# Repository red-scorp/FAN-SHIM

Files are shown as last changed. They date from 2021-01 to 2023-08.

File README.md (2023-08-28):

# FAN-SHIM project

FAN-SHIM (mini-HAT), support board for axial fans to cool Raspberry Pi.

Some Pis not require cooling because their CPUs are running in low performance mode.
Some Pis are good with simple passive heat sinks alone.
It's generally recommended to use active coolers, specially if you run Pi's CPU over-clocked.

This boards are designed to be used with standard axial funs with Pi's "Dupont" and standard PC's "Molex" connectors.

## FAN-zero30-SHIM

Raspberry Pi zero 40-pin **FAN-zero30-SHIM** mini-HAT.

Preview:

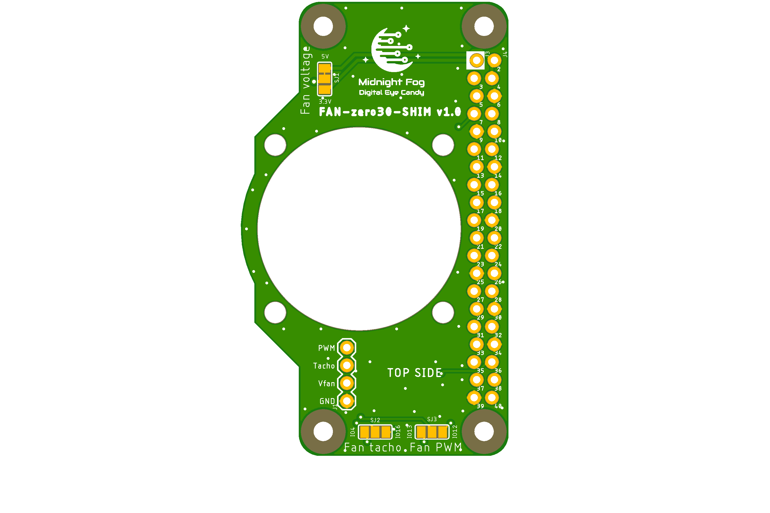
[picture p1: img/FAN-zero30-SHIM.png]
FAN-zero30-SHIM preview


[Schematics in PDF format](doc/FAN-zero30-SHIM.pdf)

Features:

- locked Pi headers
- 30mm axial fan
- 5V and 3.3V fan power selection
- fan tacho and PWM signal selection
- Pi zero board style
- can be used as SHIM (no headers) or HAT (with headers)

Pins Configuration:

|Fan Pin |Option 1 |Option 2 |
|---|---|---|
|Vfan |5V\* |3.3V |
|tacho |GPIO16 |GPIO4 |
|PWM |GPIO12 |GPIO13 |

\*) the pin is connected by default.

CAM files are available.

## FAN-zero25-SHIM

Raspberry Pi zero 40-pin **FAN-zero25-SHIM** mini-HAT.

Preview:

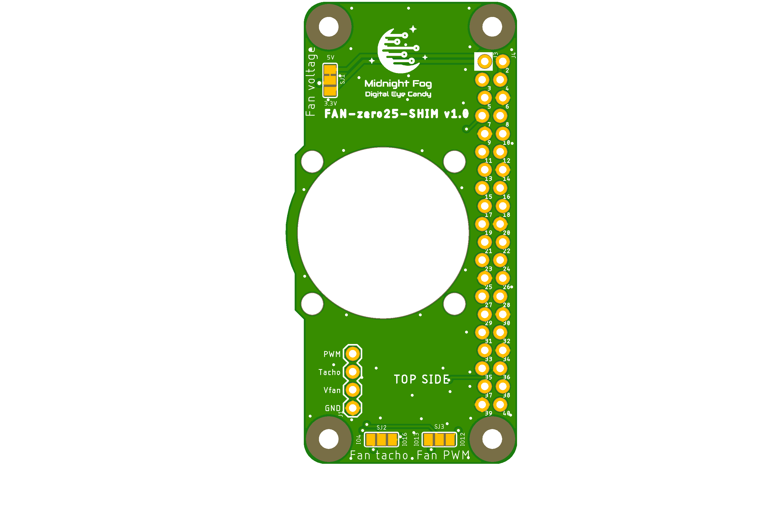
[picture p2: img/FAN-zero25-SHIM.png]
FAN-zero25-SHIM preview


[Schematics in PDF format](doc/FAN-zero25-SHIM.pdf)

Features:

- locked Pi headers
- 25mm axial fan
- 5V and 3.3V fan power selection
- fan tacho and PWM signal selection
- Pi zero board style
- can be used as SHIM (no headers) or HAT (with headers)

Pins Configuration:

|Fan Pin |Option 1 |Option 2 |
|---|---|---|
|Vfan |5V\* |3.3V |
|tacho |GPIO16 |GPIO4 |
|PWM |GPIO12 |GPIO13 |

\*) the pin is connected by default.

CAM files are available.

## FAN-zero20-SHIM

Raspberry Pi zero 40-pin **FAN-zero20-SHIM** mini-HAT.

Preview:

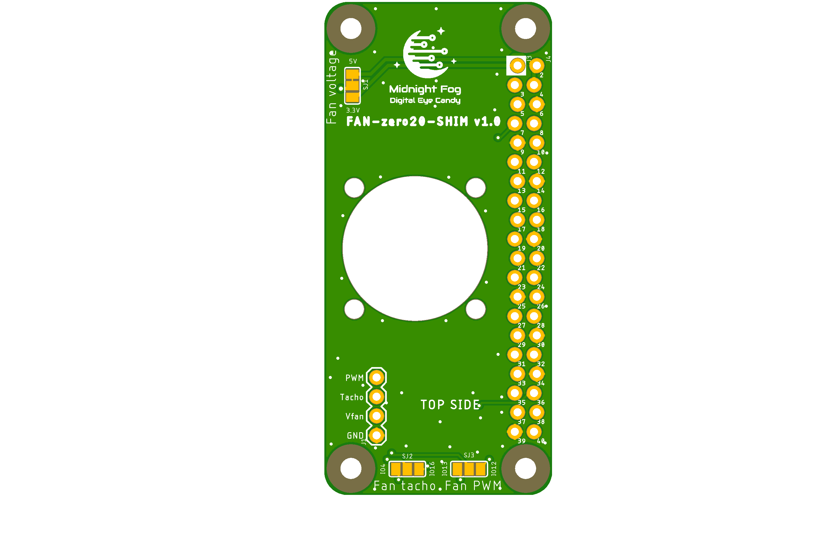
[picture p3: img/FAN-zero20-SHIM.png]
FAN-zero20-SHIM preview


[Schematics in PDF format](doc/FAN-zero20-SHIM.pdf)

Features:

- locked Pi headers
- 20mm axial fan
- 5V and 3.3V fan power selection
- fan tacho and PWM signal selection
- Pi zero board style
- can be used as SHIM (no headers) or HAT (with headers)

Pins Configuration:

|Fan Pin |Option 1 |Option 2 |
|---|---|---|
|Vfan |5V\* |3.3V |
|tacho |GPIO16 |GPIO4 |
|PWM |GPIO12 |GPIO13 |

\*) the pin is connected by default.

CAM files are available.

## FAN-plus40-SHIM

Raspberry Pi A+/B+ 40-pin **FAN-plus40-SHIM** mini-HAT.

Preview:

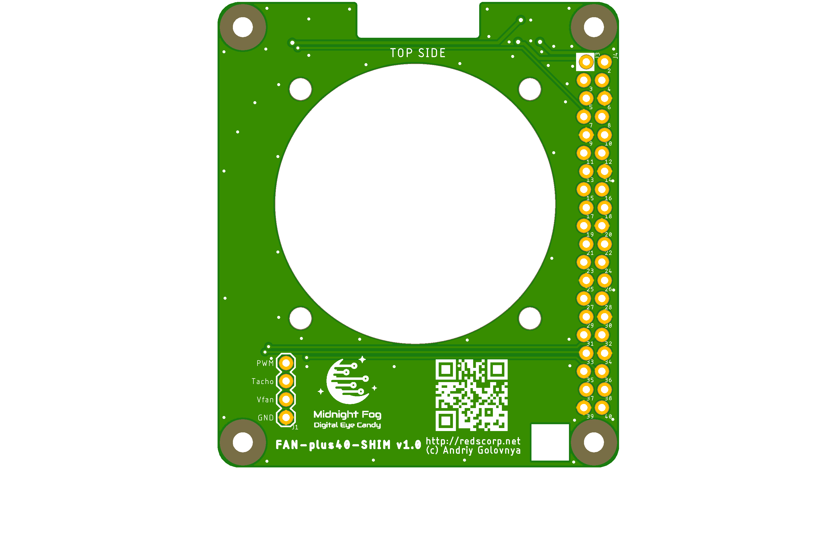
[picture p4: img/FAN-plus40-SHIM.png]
FAN-plus40-SHIM preview


[Schematics in PDF format](doc/FAN-plus40-SHIM.pdf)

Features:

- locked Pi headers
- 40mm axial fan
- 5V and 3.3V fan power selection
- fan tacho and PWM signal selection
- Pi A+/B+ board style
- can be used as SHIM (no headers) or HAT (with headers)

Pins Configuration:

|Fan Pin |Option 1 |Option 2 |
|---|---|---|
|Vfan |5V\* |3.3V |
|tacho |GPIO16 |GPIO4 |
|PWM |GPIO12 |GPIO13 |

\*) the pin is connected by default.

CAM files are available.

## FAN-plus30-SHIM

Raspberry Pi A+/B+ 40-pin **FAN-plus30-SHIM** mini-HAT.

Preview:

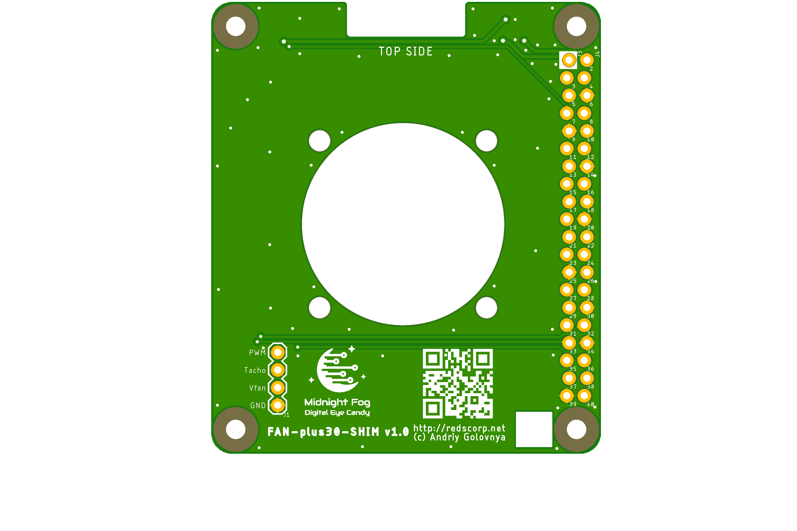
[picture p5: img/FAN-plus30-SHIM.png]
FAN-plus30-SHIM preview


[Schematics in PDF format](doc/FAN-plus30-SHIM.pdf)

Features:

- locked Pi headers
- 30mm axial fan
- 5V and 3.3V fan power selection
- fan tacho and PWM signal selection
- Pi A+/B+ board style
- can be used as SHIM (no headers) or HAT (with headers)

Pins Configuration:

|Fan Pin |Option 1 |Option 2 |
|---|---|---|
|Vfan |5V\* |3.3V |
|tacho |GPIO16 |GPIO4 |
|PWM |GPIO12 |GPIO13 |

\*) the pin is connected by default.

CAM files are available.

## Links

- [pinout.xyz](https://pinout.xyz/) - a brilliant resource on topic of Pi's pinout and HATs.
- [raspberrypi/hats](https://github.com/raspberrypi/hats) - Pi's HAT specification.

## How to help

Your contributions as code, resources, or finances are welcome! Please contact me directly via email at andriy.golovnya@gmail.com or through my [GitHub profile](https://github.com/red-scorp).

If you'd like to make a financial contribution, you can donate via [PayPal](http://paypal.me/redscorp) or [Ko-Fi](http://ko-fi.com/redscorp). Your support is greatly appreciated.

Thanks in advance!

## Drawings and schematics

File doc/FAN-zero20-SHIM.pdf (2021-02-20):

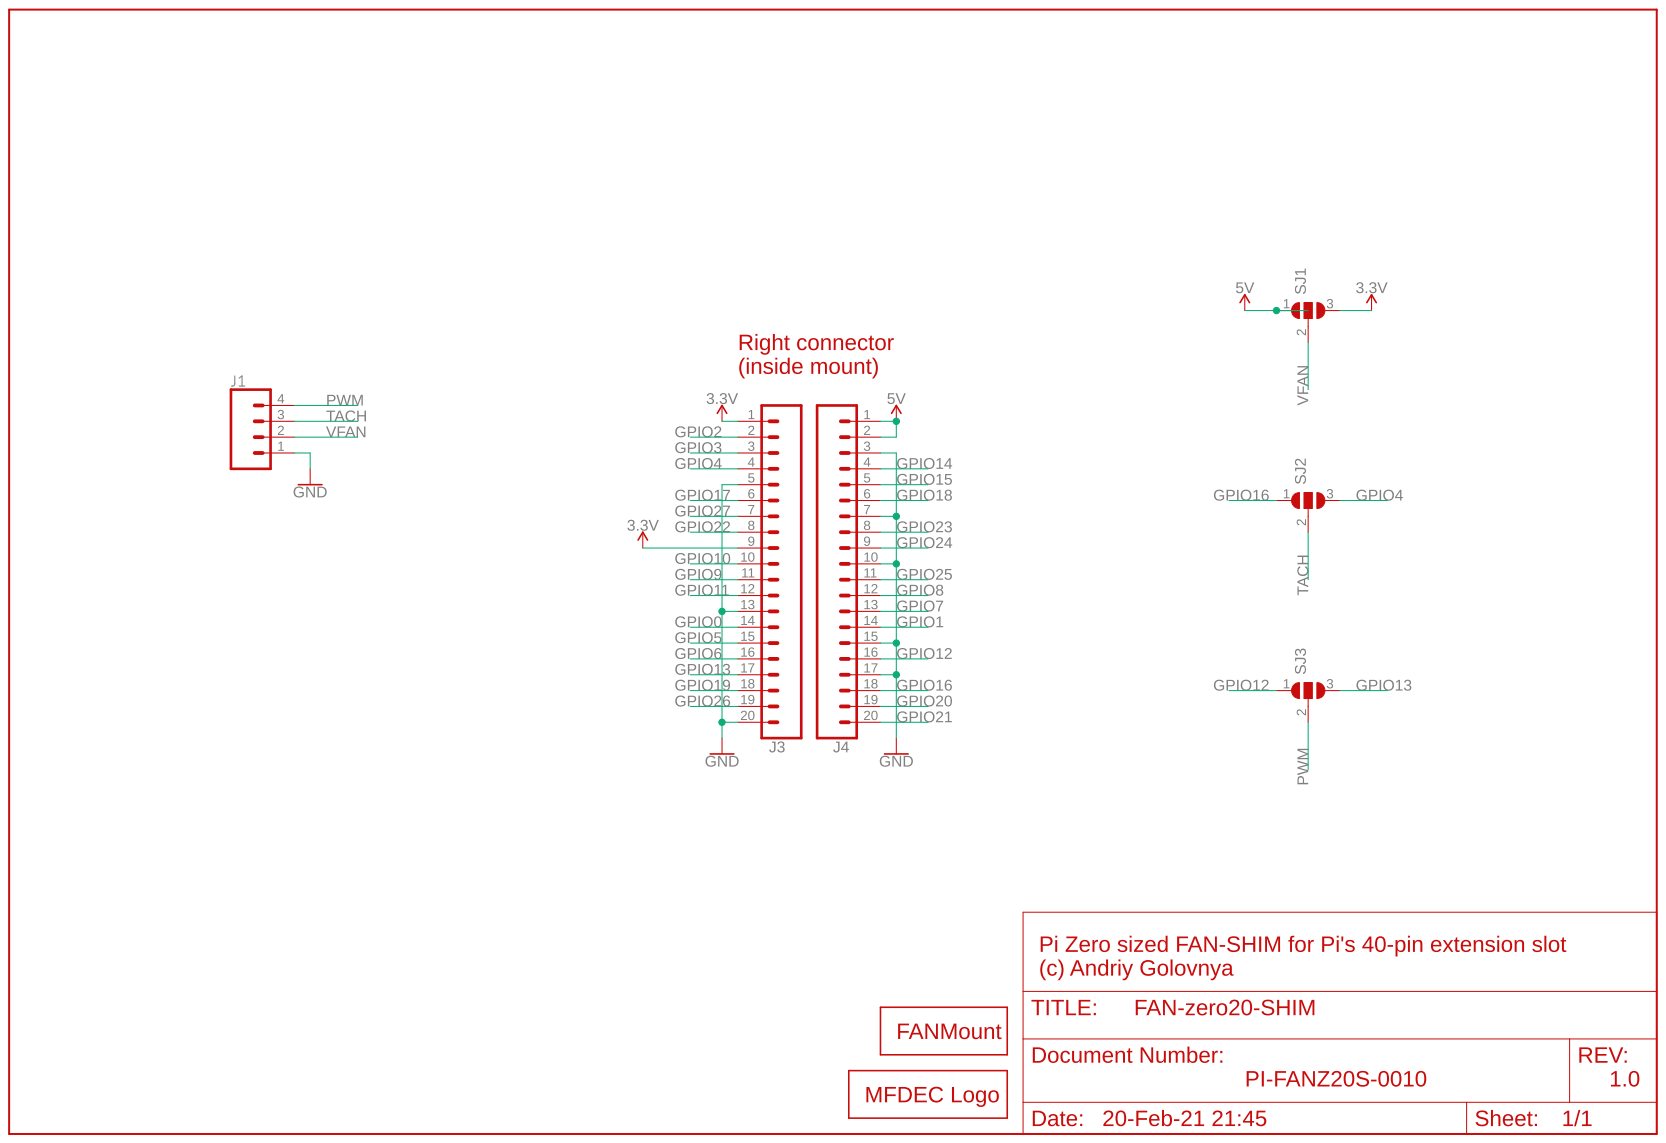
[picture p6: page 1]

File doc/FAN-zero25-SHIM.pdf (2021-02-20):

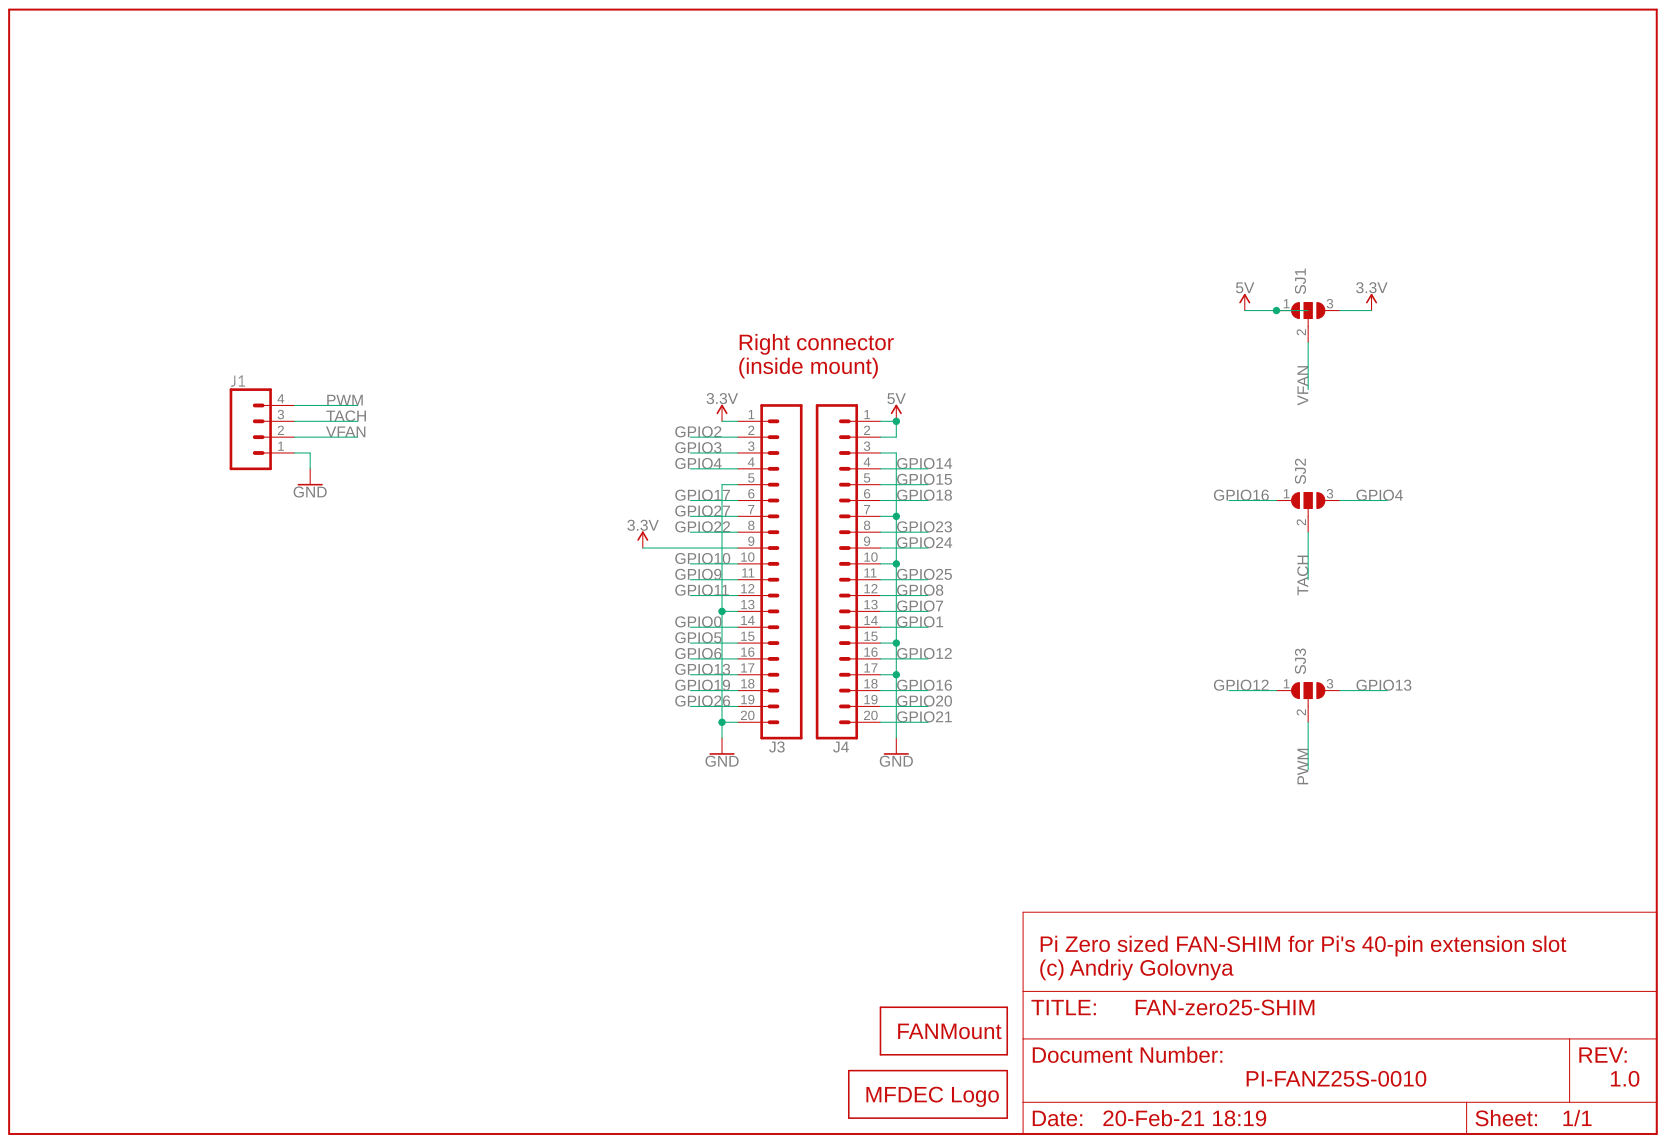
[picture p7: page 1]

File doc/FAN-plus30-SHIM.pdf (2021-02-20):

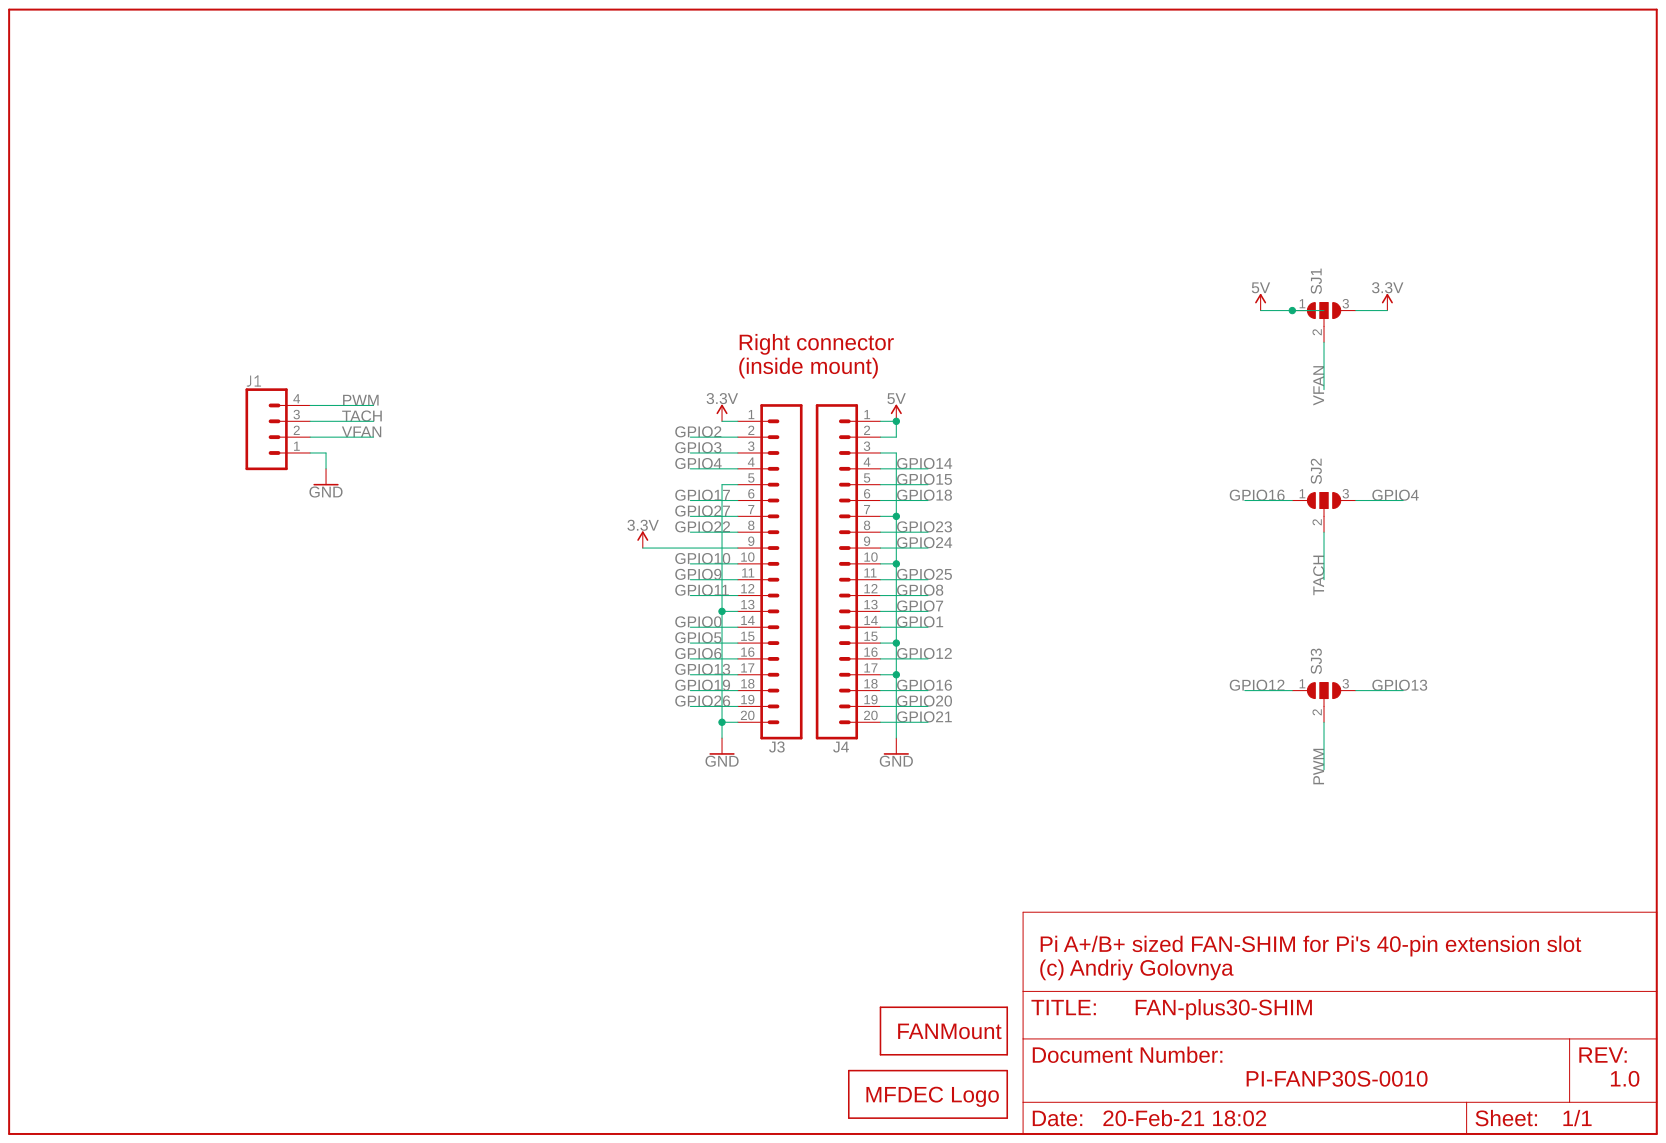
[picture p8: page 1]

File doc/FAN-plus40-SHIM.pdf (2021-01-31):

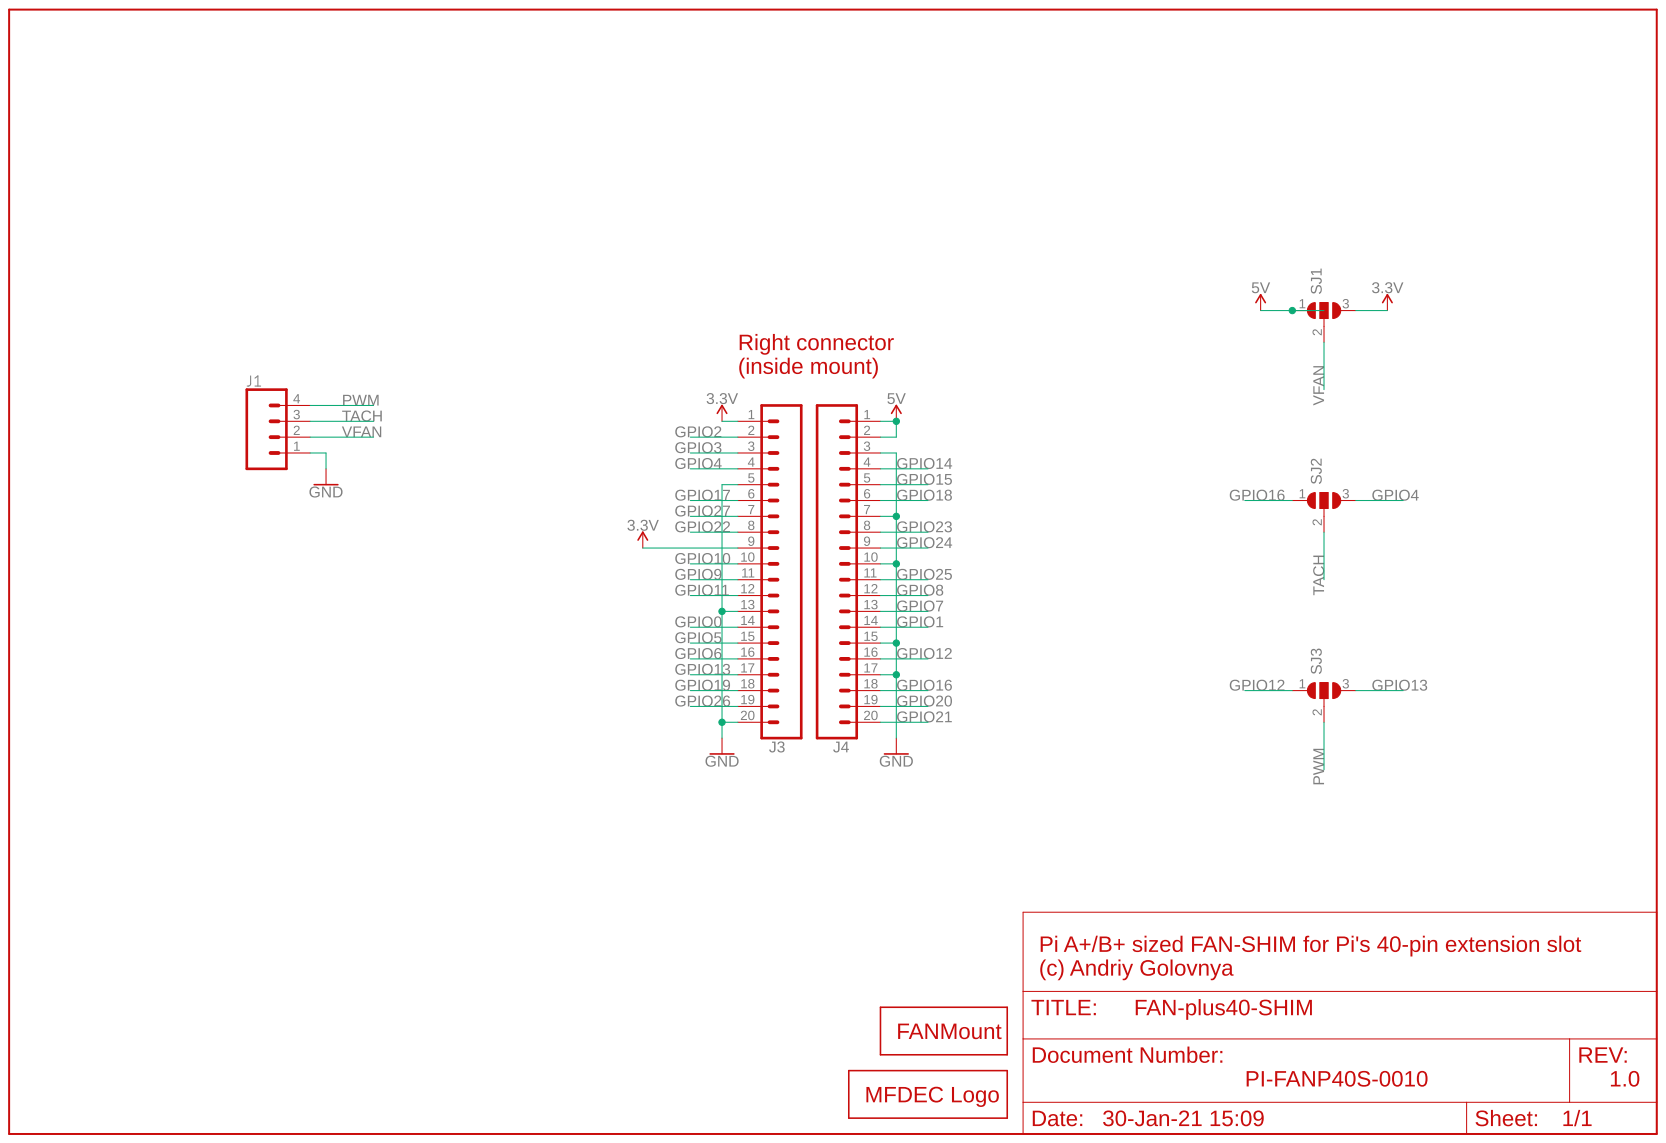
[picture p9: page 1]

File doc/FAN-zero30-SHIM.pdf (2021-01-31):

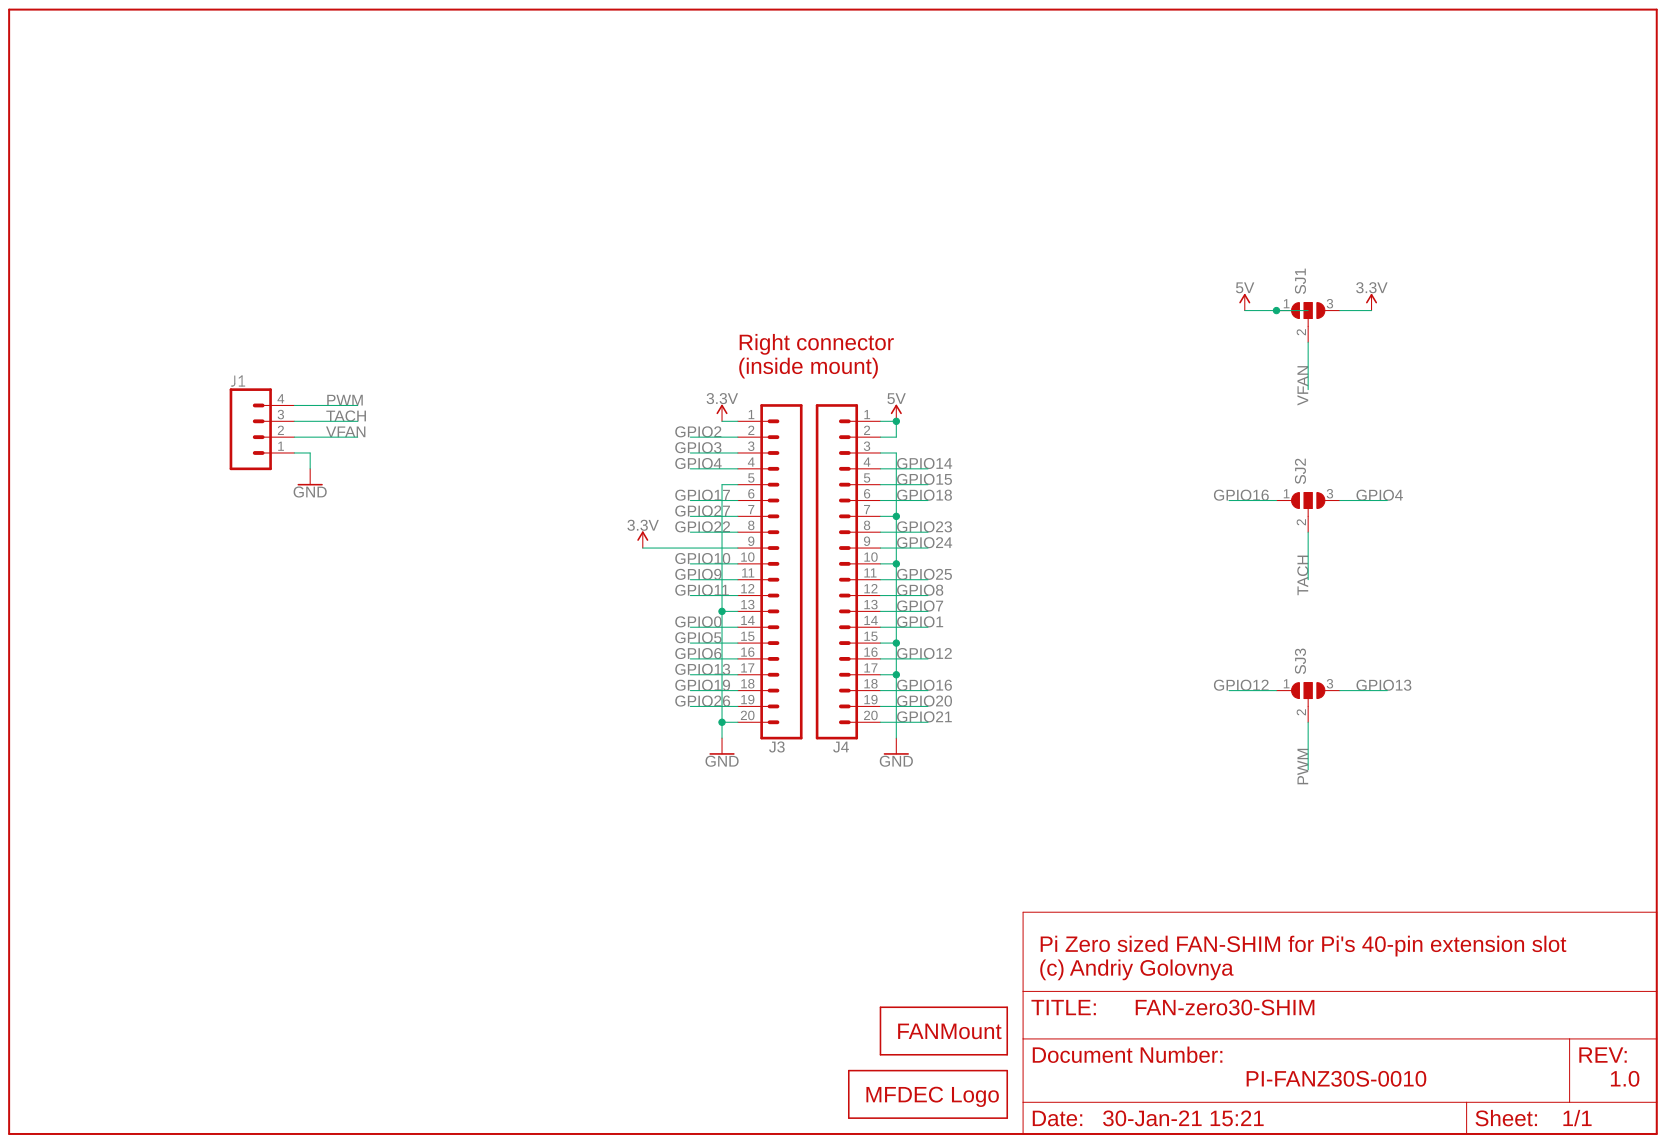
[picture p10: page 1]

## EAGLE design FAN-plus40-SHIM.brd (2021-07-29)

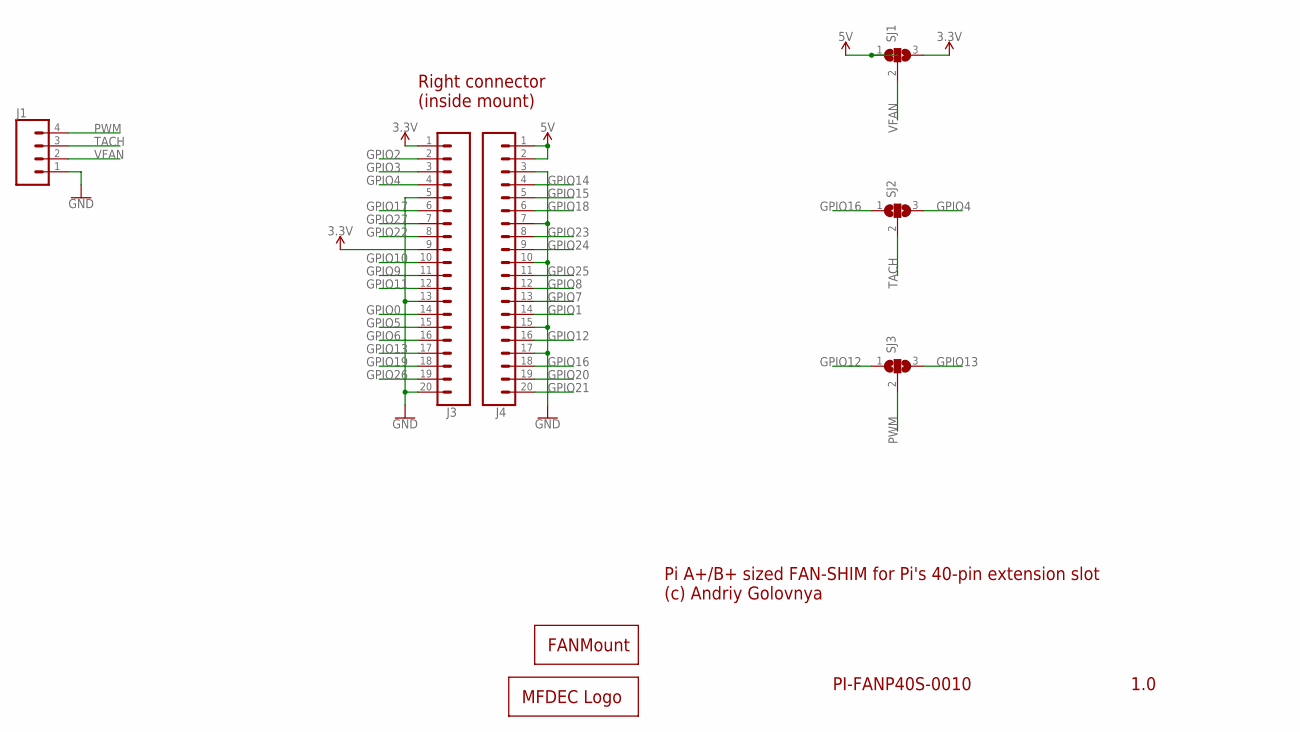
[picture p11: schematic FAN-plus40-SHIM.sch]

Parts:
FAN1: FAN40HO
J1: CONN_04; 1X04
J3, J4: CONN_20LOCK; 1X20_LOCK
LOGO1: MFDECLOGO_L_40MM; MFDEC_L_40MM
SJ1, SJ2, SJ3: SJ2; SJ_2

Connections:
3.3V: J3.1, J3.9, SJ1.3
5V: J4.1, J4.2, SJ1.1
GND: J1.1, J3.5, J3.13, J3.20, J4.3, J4.7, J4.10, J4.15, J4.17
GPIO0: J3.14
GPIO1: J4.14
GPIO2: J3.2
GPIO3: J3.3
GPIO4: J3.4, SJ2.3
GPIO5: J3.15
GPIO6: J3.16
GPIO7: J4.13
GPIO8: J4.12
GPIO9: J3.11
GPIO10: J3.10
GPIO11: J3.12
GPIO12: J4.16, SJ3.1
GPIO13: J3.17, SJ3.3
GPIO14: J4.4
GPIO15: J4.5
GPIO16: J4.18, SJ2.1
GPIO17: J3.6
GPIO18: J4.6
GPIO19: J3.18
GPIO20: J4.19
GPIO21: J4.20
GPIO22: J3.8
GPIO23: J4.8
GPIO24: J4.9
GPIO25: J4.11
GPIO26: J3.19
GPIO27: J3.7
PWM: J1.4, SJ3.2
TACH: J1.3, SJ2.2
VFAN: J1.2, SJ1.2

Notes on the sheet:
1.0
PI-FANP40S-0010
Pi A+/B+ sized FAN-SHIM for Pi's 40-pin extension slot (c) Andriy Golovnya
Right connector (inside mount)

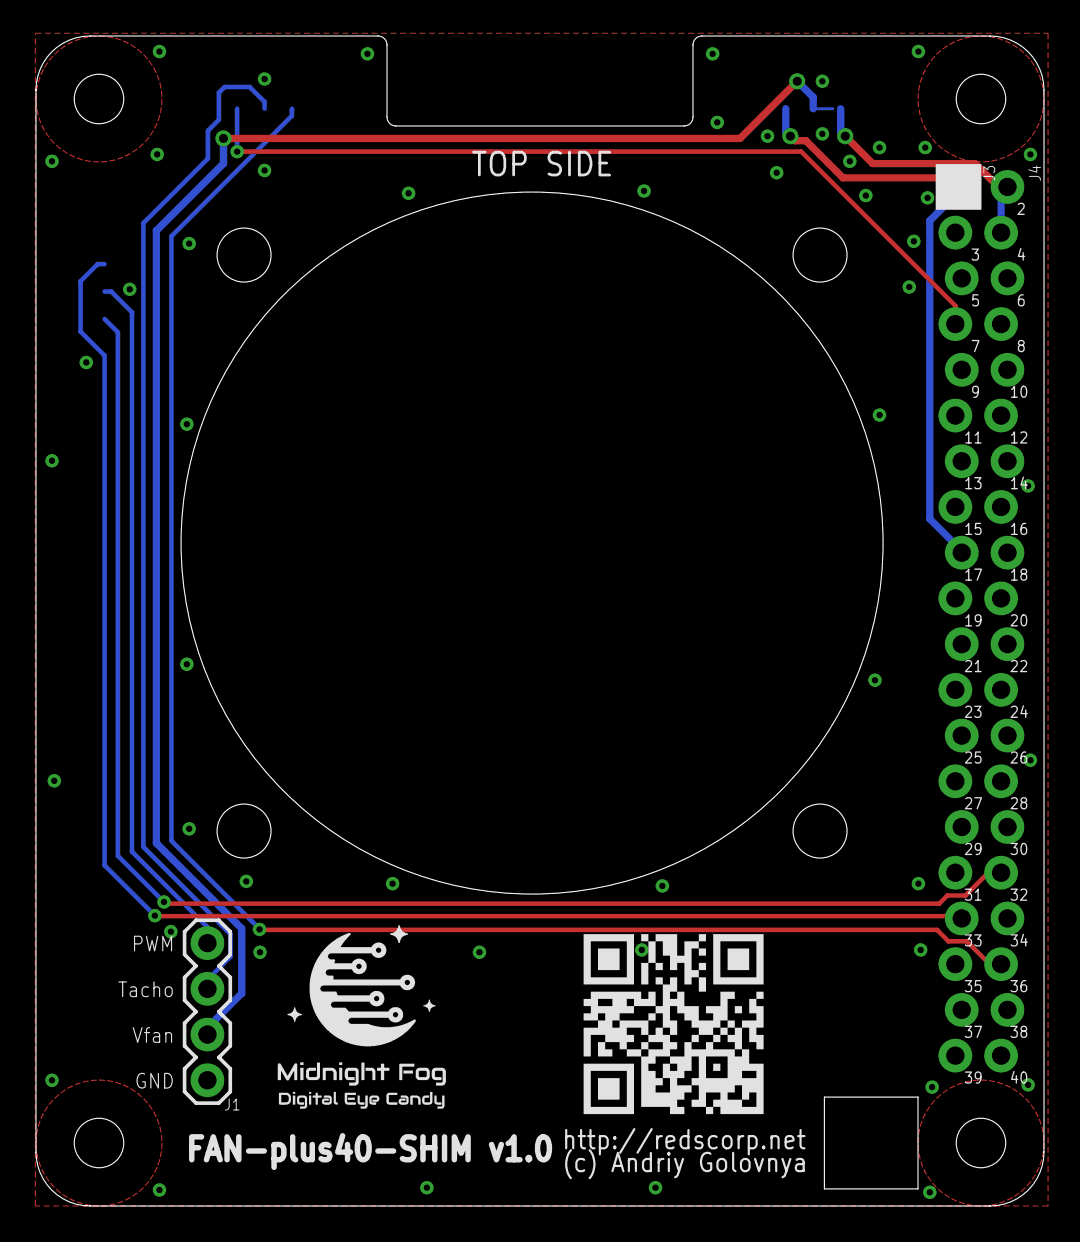
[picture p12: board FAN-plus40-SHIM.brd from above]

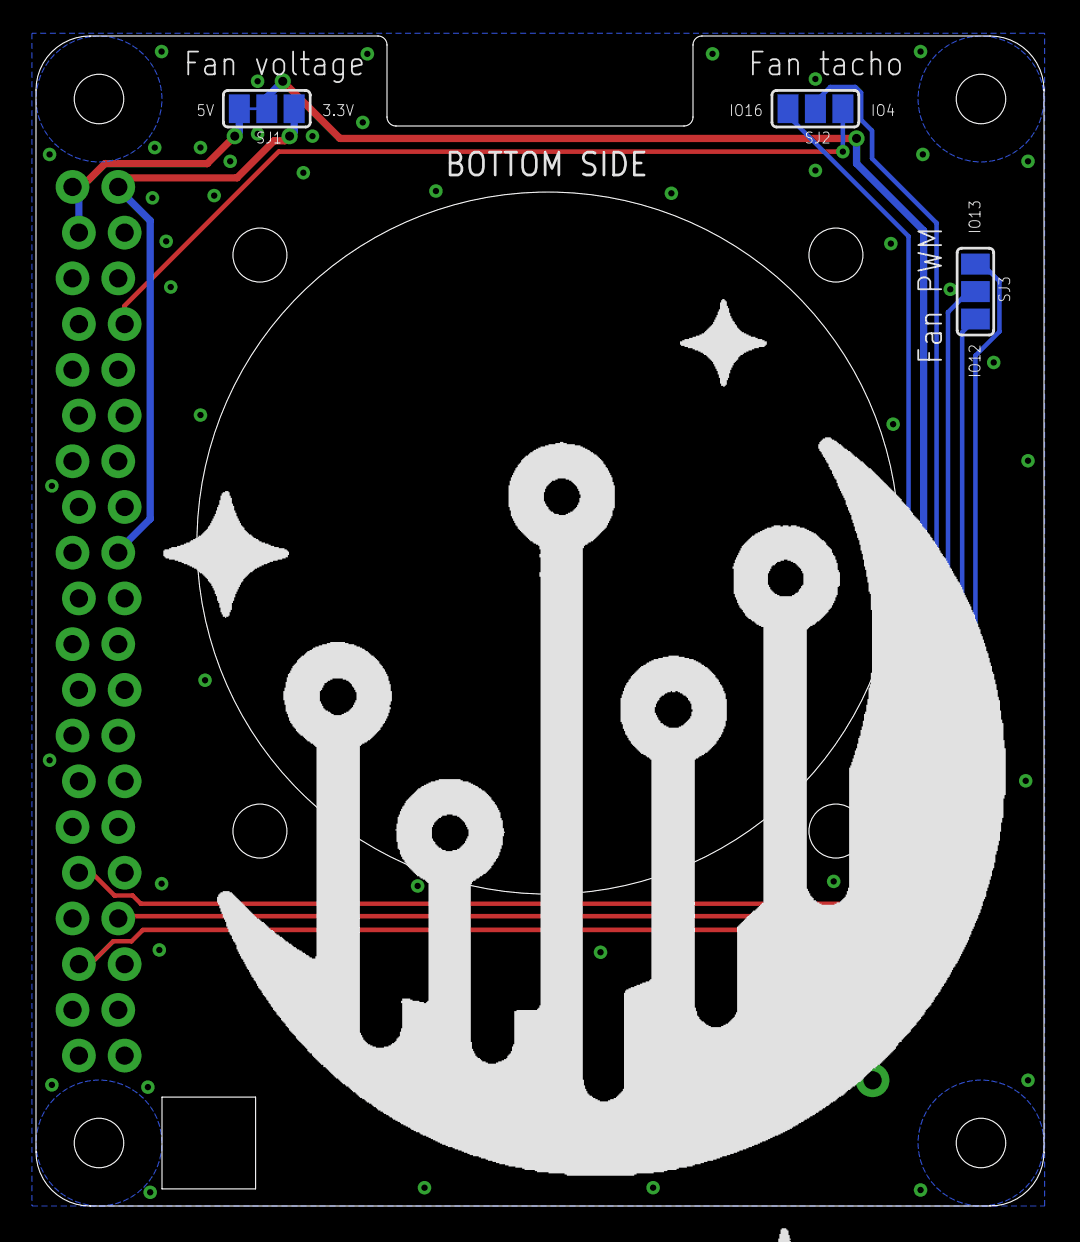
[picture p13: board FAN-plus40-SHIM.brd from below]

Board: 2 copper layers, 56.0 x 65.0 mm, 10 parts (4 on the bottom side), 10 nets.

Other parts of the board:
LOGO2: MFDECLOGO_SQ_8MM; MFDEC_SQ_8MM
LOGO3: RSNURL_QR_10MM

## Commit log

2021-01-24 Added basic placement for zero board
    [FAN-zero-SHIM.brd, FAN-zero-SHIM.sch]
2021-01-30 Shaped FAN-zero-SHIM size.
    [FAN-zero-SHIM.brd]
2021-01-30 Renamed boards according to fan sizes.
    [FAN-plus40-SHIM.brd, FAN-plus40-SHIM.sch, FAN-zero30-SHIM.brd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]
2021-01-30 Connecting dots.
    [FAN-plus40-SHIM.brd, FAN-plus40-SHIM.sch, FAN-zero30-SHIM.brd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]
2021-01-31 Moved some traces around.
    [FAN-zero30-SHIM.brd]
2021-01-31 Generated CAM. Generated PDF schematics. Generated PNG preview images.
2021-02-19 - Fixed 30mm fan mount hole distance. - Generated new CAM. - Generated new PNG preview image.
    [FAN-zero30-SHIM.brd, FAN-zero30-SHIM.sch]
2021-02-20 - Fixed VFAN trace on zero30 board. - Generated new CAM. - Generated new PNG preview image.
    [FAN-zero30-SHIM.brd]
2021-02-20 - Add 30mm plus version of the board. - Generated CAM. - Generated PNG preview. - Generated PDF schematics. - Updated descriptions.
    [FAN-plus30-SHIM.brd, FAN-plus30-SHIM.sch]
2021-02-20 - Add 25mm zero version of the board. - Generated CAM. - Generated PNG preview. - Generated PDF schematics. - Updated descriptions.
    [FAN-zero25-SHIM.brd, FAN-zero25-SHIM.sch]
2021-02-20 - Add 20mm zero version of the board. - Generated CAM. - Generated PNG preview. - Generated PDF schematics. - Updated descriptions.
    [FAN-zero20-SHIM.brd, FAN-zero20-SHIM.sch]
2021-02-20 - Fixed power trace on zero30 board. - Generated new CAM.
    [FAN-zero25-SHIM.brd]
2021-07-29 Make round cutouts in screwing area. Generated CAM files. Generated PNG previews.
    [FAN-plus30-SHIM.brd, FAN-plus40-SHIM.brd, FAN-zero20-SHIM.brd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]

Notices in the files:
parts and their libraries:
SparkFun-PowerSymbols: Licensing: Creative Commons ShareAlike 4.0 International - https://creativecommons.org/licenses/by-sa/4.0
